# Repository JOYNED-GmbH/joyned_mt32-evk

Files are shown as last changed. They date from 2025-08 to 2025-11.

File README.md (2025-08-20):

This is a hardware reference design for a fully compliant Milan endpoint. It converts from a AVB/Milan network to I2S or TDM and vice versa.
Please feel free to copy and modify for your individual needs. This hardware reference design is published under the Creative Commons License. For software licensing visit www.joyned.at

Portmap Spreadsheet: https://docs.google.com/spreadsheets/d/1wGiAsmqoAx-SCyp8chBWGLcsXNjXNMac/edit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

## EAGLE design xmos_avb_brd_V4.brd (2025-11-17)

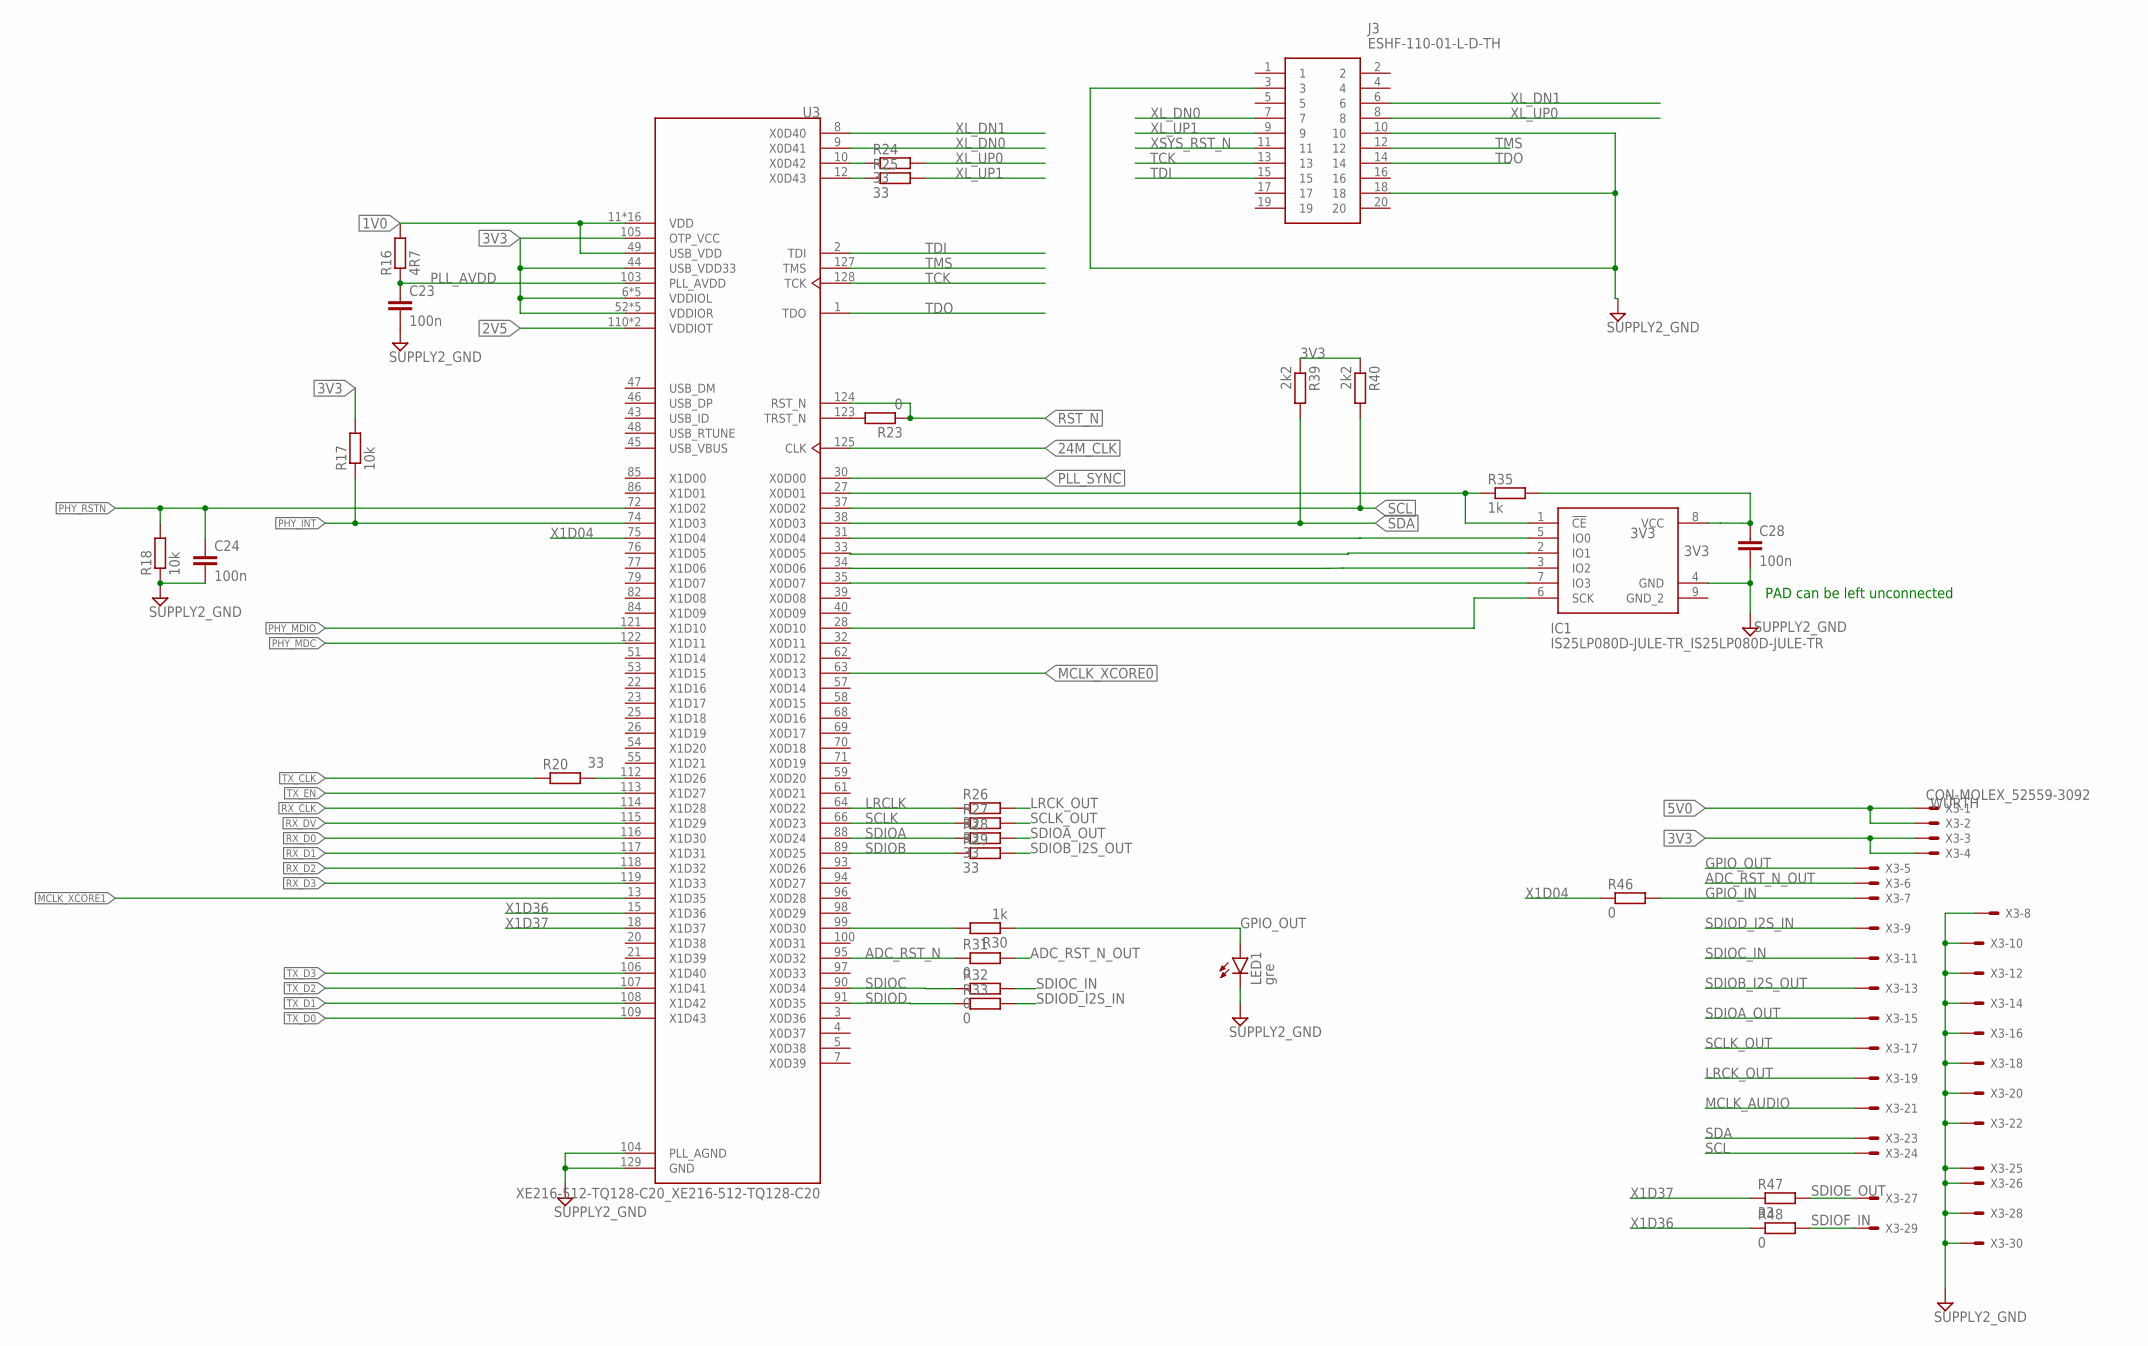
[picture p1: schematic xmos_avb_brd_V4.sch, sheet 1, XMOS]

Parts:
C23, C24, C28: 100n; RCL_C0402
IC1: IS25LP080D-JULE-TR_IS25LP080D-JULE-TR; IS25LP080D-JULE-TR_SON50P300X200X55-9N
J3: ESHF-110-01-L-D-TH; SHDR20W41P127_2X10_1905X559X54
LED1: gre; LED_CHIP-LED0603
R16: 4R7; RCL_R0402
R17, R18: 10k; RCL_R0402
R20, R24, R25, R26, R27, R28, R29, R47: 33; RCL_R0402
R23, R31, R32, R33, R46, R48: 0; RCL_R0402
R30, R35: 1k; RCL_R0402
R39, R40: 2k2; RCL_R0402
U3: XE216-512-TQ128-C20_XE216-512-TQ128-C20; XE216-512-TQ128-C20_QFP40P1600X1600X120-129N
X3: CON-MOLEX_52559-3092; MPN 687330124422

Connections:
1V0: R16.2, U3.11 (VDD), U3.16 (VDD), U3.17 (VDD), U3.24 (VDD), U3.36 (VDD), U3.41 (VDD), U3.49 (USB_VDD), U3.56 (VDD), U3.60 (VDD), U3.73 (VDD), U3.80 (VDD), U3.81 (VDD), U3.87 (VDD), U3.101 (VDD), U3.102 (VDD), U3.120 (VDD), U3.126 (VDD); also elsewhere on the board
2V5: U3.110 (VDDIOT), U3.111 (VDDIOT); also elsewhere on the board
3V3: C28.1, IC1.8 (VCC), R17.2, R35.2, R39.1, R40.1, U3.6 (VDDIOL), U3.14 (VDDIOL), U3.19 (VDDIOL), U3.29 (VDDIOL), U3.42 (VDDIOL), U3.44 (USB_VDD33), U3.52 (VDDIOR), U3.67 (VDDIOR), U3.78 (VDDIOR), U3.83 (VDDIOR), U3.92 (VDDIOR), U3.105 (OTP_VCC), X3.3, X3.4; also elsewhere on the board
5V0: X3.1, X3.2; also elsewhere on the board
24M_CLK: U3.125 (CLK); also elsewhere on the board
ADC_RST_N: R31.1, U3.95 (X0D32)
ADC_RST_N_OUT: R31.2, X3.6
GND: C23.2, C24.2, C28.2, IC1.4 (GND), J3.3, J3.10, J3.18, LED1.C, R18.1, U3.104 (PLL_AGND), U3.129 (GND), X3.8, X3.10, X3.12, X3.14, X3.16, X3.18, X3.20, X3.22, X3.25, X3.26, X3.28, X3.30; also elsewhere on the board
GPIO_IN: R46.2, X3.7
GPIO_OUT: LED1.A, R30.1, X3.5
LRCK_OUT: R26.2, X3.19
LRCLK: R26.1, U3.64 (X0D22)
MCLK_AUDIO: X3.21; also elsewhere on the board
MCLK_XCORE0: U3.63 (X0D13); also elsewhere on the board
MCLK_XCORE1: U3.13 (X1D35); also elsewhere on the board
unnamed: R30.2, U3.99 (X0D30)
unnamed: IC1.6 (SCK), U3.28 (X0D10)
unnamed: IC1.5 (IO0), U3.31 (X0D04)
unnamed: IC1.2 (IO1), U3.33 (X0D05)
unnamed: IC1.3 (IO2), U3.34 (X0D06)
unnamed: R20.2, U3.112 (X1D26)
unnamed: IC1.7 (IO3), U3.35 (X0D07)
unnamed: R24.1, U3.10 (X0D42)
unnamed: R25.1, U3.12 (X0D43)
unnamed: R23.2, U3.123 (TRST_N)
PHY_INT: R17.1, U3.74 (X1D03); also elsewhere on the board
PHY_MDC: U3.122 (X1D11); also elsewhere on the board
PHY_MDIO: U3.121 (X1D10); also elsewhere on the board
PHY_RSTN: C24.1, R18.2, U3.72 (X1D02); also elsewhere on the board
PLL_AVDD: C23.1, R16.1, U3.103 (PLL_AVDD)
PLL_SYNC: U3.30 (X0D00); also elsewhere on the board
RST_N: R23.1, U3.124 (RST_N); also elsewhere on the board
RX_CLK: U3.114 (X1D28); also elsewhere on the board
RX_D0: U3.116 (X1D30); also elsewhere on the board
RX_D1: U3.117 (X1D31); also elsewhere on the board
RX_D2: U3.118 (X1D32); also elsewhere on the board
RX_D3: U3.119 (X1D33); also elsewhere on the board
RX_DV: U3.115 (X1D29); also elsewhere on the board
SCL: R40.2, U3.37 (X0D02), X3.24; also elsewhere on the board
SCLK: R27.1, U3.66 (X0D23)
SCLK_OUT: R27.2, X3.17
SDA: R39.2, U3.38 (X0D03), X3.23; also elsewhere on the board
SDIOA: R28.1, U3.88 (X0D24)
SDIOA_OUT: R28.2, X3.15
SDIOB: R29.1, U3.89 (X0D25)
SDIOB_I2S_OUT: R29.2, X3.13
SDIOC: R32.1, U3.90 (X0D34)
SDIOC_IN: R32.2, X3.11
SDIOD: R33.1, U3.91 (X0D35)
SDIOD_I2S_IN: R33.2, X3.9
SDIOE_OUT: R47.2, X3.27
SDIOF_IN: R48.2, X3.29
SPI_CS: IC1.1 (!CE), R35.1, U3.27 (X0D01)
TCK: J3.13, U3.128 (TCK)
TDI: J3.15, U3.2 (TDI)
TDO: J3.14, U3.1 (TDO)
TMS: J3.12, U3.127 (TMS)
TX_CLK: R20.1; also elsewhere on the board
TX_D0: U3.109 (X1D43); also elsewhere on the board
TX_D1: U3.108 (X1D42); also elsewhere on the board
TX_D2: U3.107 (X1D41); also elsewhere on the board
TX_D3: U3.106 (X1D40); also elsewhere on the board
TX_EN: U3.113 (X1D27); also elsewhere on the board
X1D04: R46.1, U3.75 (X1D04)
X1D36: R48.1, U3.15 (X1D36)
X1D37: R47.1, U3.18 (X1D37)
XL_DN0: J3.7, U3.9 (X0D41)
XL_DN1: J3.6, U3.8 (X0D40)
XL_UP0: J3.8, R24.2
XL_UP1: J3.9, R25.2
XSYS_RST_N: J3.11; also elsewhere on the board

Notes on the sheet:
PAD can be left unconnected

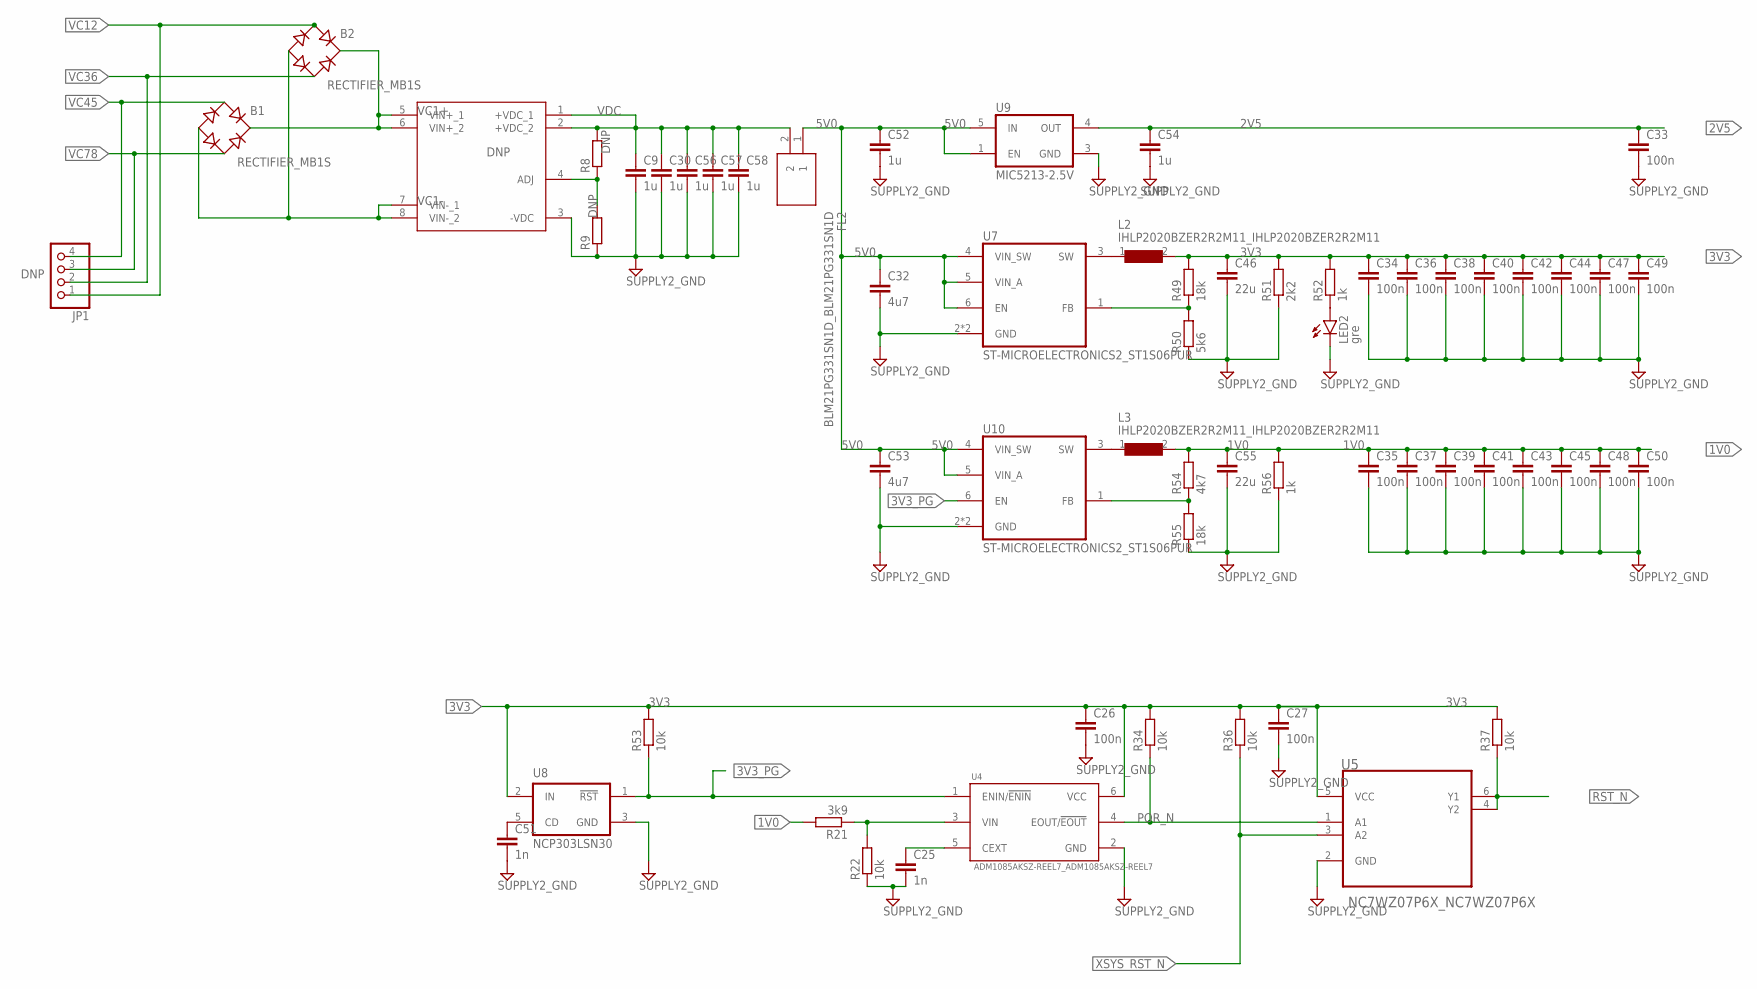
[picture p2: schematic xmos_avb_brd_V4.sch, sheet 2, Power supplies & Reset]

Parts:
B1, B2: RECTIFIER_MB1S; RECTIFIER_SOIC-4
C9, C30, C52, C54, C56, C57, C58: 1u; RCL_C1206
C25, C51: 1n; RCL_C0402
C26, C27, C33, C34, C35, C36, C37, C38, C39, C40, C41, C42, C43, C44, C45, C47, C48, C49, C50: 100n; RCL_C0402
C32, C53: 4u7; RCL_C1206
C46, C55: 22u; RCL_C1206
FL2: BLM21PG331SN1D_BLM21PG331SN1D; BLM21PG331SN1D_BEADC2012X105N
JP1: PINHEAD_PINHD-1X4; PINHEAD_1X04
L2, L3: IHLP2020BZER2R2M11_IHLP2020BZER2R2M11; IHLP2020BZER2R2M11_INDPM5552X200N
LED2: gre; LED_CHIP-LED0603
R8, R9: RCL_R-EU_R0402; RCL_R0402
R21: 3k9; RCL_R0402
R22, R34, R36, R37, R53: 10k; RCL_R0402
R49, R55: 18k; RCL_R0402
R50: 5k6; RCL_R0402
R51: 2k2; RCL_R0402
R52, R56: 1k; RCL_R0402
R54: 4k7; RCL_R0402
U1: AG9900_AG9905LP; AG9900_AG9900LP
U4: ADM1085AKSZ-REEL7_ADM1085AKSZ-REEL7; ADM1085AKSZ-REEL7_SOP65P210X95-6N
U5: NC7WZ07P6X_NC7WZ07P6X; NC7WZ07P6X_SOT65P210X110-6N
U7, U10: ST-MICROELECTRONICS2_ST1S06PUR; ST-MICROELECTRONICS2_DFN6
U8: NCP303LSN30; ON-SEMI_SOT23-5
U9: MIC5213-2.5V; MICREL2_SC70-5

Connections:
1V0: C35.1, C37.1, C39.1, C41.1, C43.1, C45.1, C48.1, C50.1, C55.1, L3.2, R21.2, R54.2, R56.2; also elsewhere on the board
2V5: C33.1, C54.1, U9.4 (OUT); also elsewhere on the board
3V3: C26.1, C27.1, C34.1, C36.1, C38.1, C40.1, C42.1, C44.1, C46.1, C47.1, C49.1, L2.2, R34.2, R36.2, R37.2, R49.2, R51.2, R52.2, R53.2, U4.6 (VCC), U5.5 (VCC), U8.2 (IN); also elsewhere on the board
3V3_PG: R53.1, U4.1 (ENIN/!ENIN), U8.1 (!RST!), U10.6 (EN)
5V0: C32.1, C52.1, C53.1, FL2.1, U7.4 (VIN_SW), U7.5 (VIN_A), U7.6 (EN), U9.1 (EN), U9.5 (IN), U10.4 (VIN_SW), U10.5 (VIN_A); also elsewhere on the board
GND: C9.2, C25.2, C26.2, C27.2, C30.2, C32.2, C33.2, C34.2, C35.2, C36.2, C37.2, C38.2, C39.2, C40.2, C41.2, C42.2, C43.2, C44.2, C45.2, C46.2, C47.2, C48.2, C49.2, C50.2, C51.2, C52.2, C53.2, C54.2, C55.2, C56.2, C57.2, C58.2, LED2.C, R9.1, R22.1, R50.1, R51.1, R55.1, R56.1, U1.3 (-VDC), U4.2 (GND), U5.2 (GND), U7.2 (GND), U7.7 (GND), U8.3 (GND), U9.3 (GND), U10.2 (GND), U10.7 (GND); also elsewhere on the board
unnamed: R21.1, R22.2, U4.3 (VIN)
unnamed: R8.1, R9.2, U1.4 (ADJ)
unnamed: L2.1, U7.3 (SW)
unnamed: L3.1, U10.3 (SW)
unnamed: C25.1, U4.5 (CEXT)
unnamed: R54.1, R55.2, U10.1 (FB)
unnamed: C51.1, U8.5 (CD)
unnamed: R49.1, R50.2, U7.1 (FB)
unnamed: LED2.A, R52.1
POR_N: R34.1, U4.4 (EOUT/!EOUT), U5.1 (A1)
RST_N: R37.1, U5.4 (Y2), U5.6 (Y1); also elsewhere on the board
VC1+: B1.+, B2.+, U1.5 (VIN+_1), U1.6 (VIN+_2)
VC1-: B1.-, B2.-, U1.7 (VIN-_1), U1.8 (VIN-_2)
VC12: B2.~1 (AC1), JP1.1; also elsewhere on the board
VC36: B2.~2 (AC2), JP1.2; also elsewhere on the board
VC45: B1.~1 (AC1), JP1.4; also elsewhere on the board
VC78: B1.~2 (AC2), JP1.3; also elsewhere on the board
VDC: C9.1, C30.1, C56.1, C57.1, C58.1, FL2.2, R8.2, U1.1 (+VDC_1), U1.2 (+VDC_2)
XSYS_RST_N: R36.1, U5.3 (A2); also elsewhere on the board

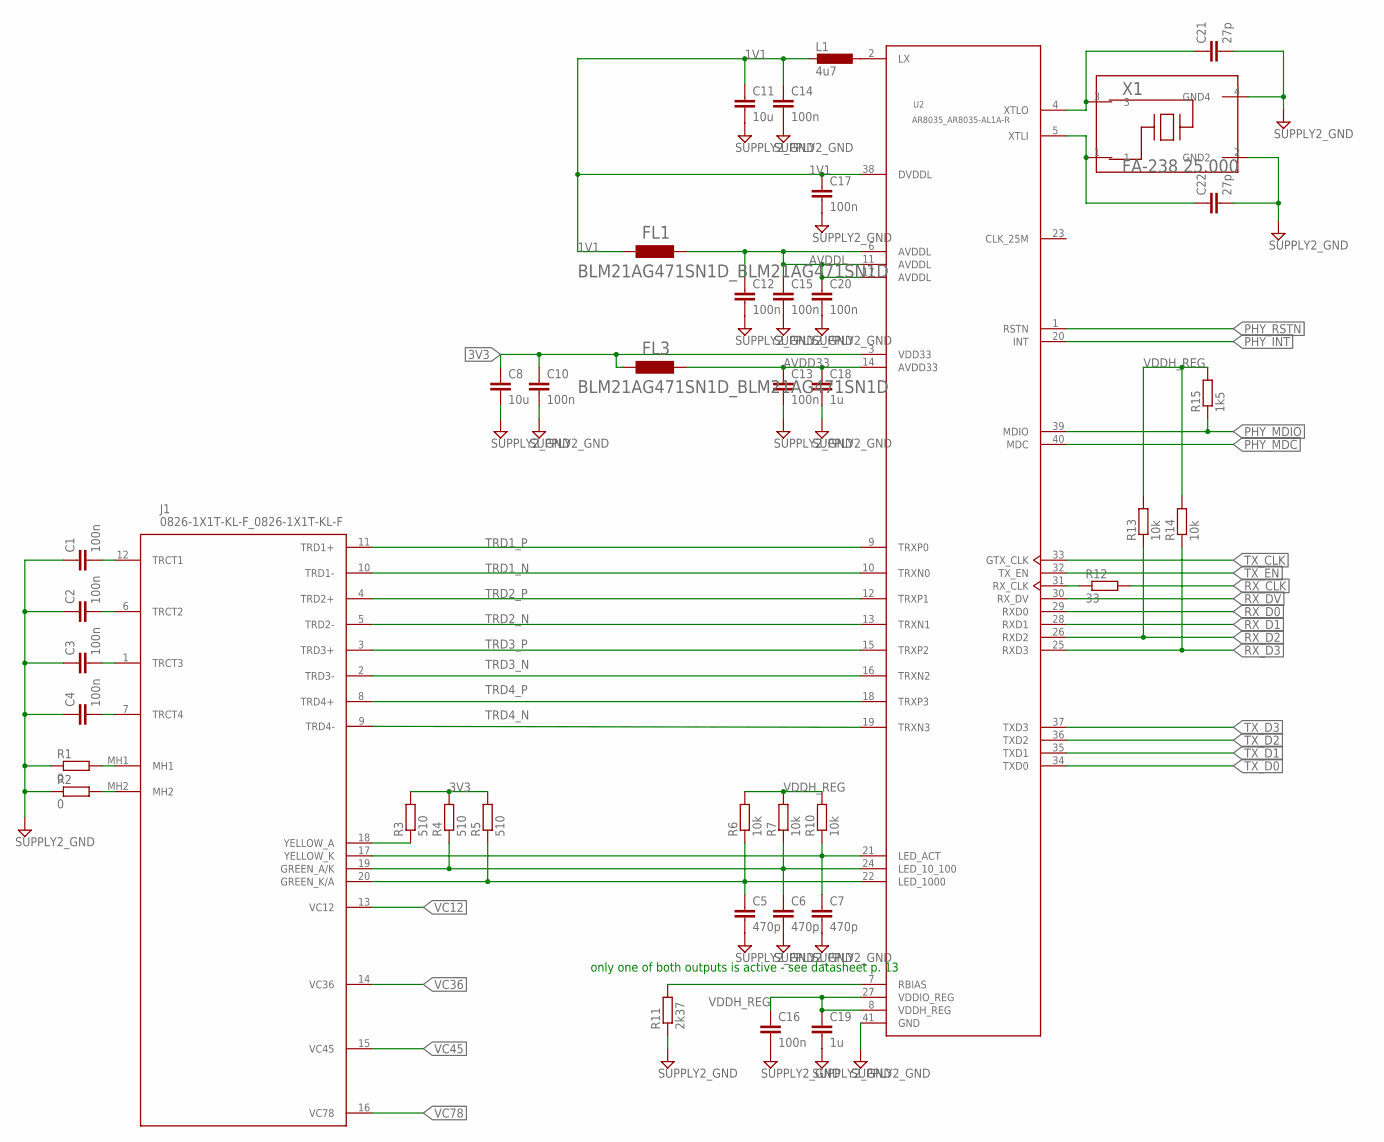
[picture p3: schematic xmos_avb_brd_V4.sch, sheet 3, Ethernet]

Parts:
C1, C2, C3, C4, C10, C12, C13, C14, C15, C16, C17, C20: 100n; RCL_C0402
C5, C6, C7: 470p; RCL_C0402
C8, C11: 10u; RCL_C1206
C18, C19: 1u; RCL_C1206
C21, C22: 27p; RCL_C0402
FL1, FL3: BLM21AG471SN1D_BLM21AG471SN1D; BLM21AG471SN1D_BEADC2012X105N
J1: 0826-1X1T-KL-F_0826-1X1T-KL-F; 0826-1X1T-KL-F_08261X1TKLF
L1: 4u7; RCL_L2012C
R1, R2: 0; RCL_R0402
R3, R4, R5: 510; RCL_R0402
R6, R7, R10, R13, R14: 10k; RCL_R0402
R11: 2k37; RCL_R0402
R12: 33; RCL_R0402
R15: 1k5; RCL_R0402
U2: AR8035_AR8035-AL1A-R; AR8035_QFN40P500X500X75-41N
X1: FA-238 25.000; FA-238_OSCCC320X250X70-4N

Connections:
1V1: C11.1, C14.1, C17.1, FL1.1, L1.2, U2.38 (DVDDL)
3V3: C8.1, C10.1, FL3.1, R3.2, R4.2, R5.2, U2.3 (VDD33); also elsewhere on the board
AVDD33: C13.1, C18.1, FL3.2, U2.14 (AVDD33)
AVDDL: C12.1, C15.1, C20.1, FL1.2, U2.6 (AVDDL), U2.11 (AVDDL), U2.17 (AVDDL)
GND: C1.1, C2.1, C3.1, C4.1, C5.2, C6.2, C7.2, C8.2, C10.2, C11.2, C12.2, C13.2, C14.2, C15.2, C16.2, C17.2, C18.2, C19.2, C20.2, C21.2, C22.2, R1.1, R2.1, R11.1, U2.41 (GND), X1.2 (GND2), X1.4 (GND4); also elsewhere on the board
unnamed: L1.1, U2.2 (LX)
unnamed: J1.MH1, R1.2
unnamed: C6.1, J1.19 (GREEN_A/K), R4.1, R7.1, U2.24 (LED_10_100)
unnamed: J1.18 (YELLOW_A), R3.1
unnamed: C21.1, U2.4 (XTLO), X1.3
unnamed: C22.1, U2.5 (XTLI), X1.1
unnamed: R12.1, U2.31 (RX_CLK)
unnamed: C7.1, J1.17 (YELLOW_K), R10.1, U2.21 (LED_ACT)
unnamed: C1.2, J1.12 (TRCT1)
unnamed: C2.2, J1.6 (TRCT2)
unnamed: R11.2, U2.7 (RBIAS)
unnamed: C5.1, J1.20 (GREEN_K/A), R5.1, R6.1, U2.22 (LED_1000)
unnamed: C3.2, J1.1 (TRCT3)
unnamed: C4.2, J1.7 (TRCT4)
unnamed: J1.MH2, R2.2
PHY_INT: U2.20 (INT); also elsewhere on the board
PHY_MDC: U2.40 (MDC); also elsewhere on the board
PHY_MDIO: R15.1, U2.39 (MDIO); also elsewhere on the board
PHY_RSTN: U2.1 (RSTN); also elsewhere on the board
RX_CLK: R12.2; also elsewhere on the board
RX_D0: U2.29 (RXD0); also elsewhere on the board
RX_D1: U2.28 (RXD1); also elsewhere on the board
RX_D2: R13.1, U2.26 (RXD2); also elsewhere on the board
RX_D3: R14.1, U2.25 (RXD3); also elsewhere on the board
RX_DV: U2.30 (RX_DV); also elsewhere on the board
TRD1_N: J1.10 (TRD1-), U2.10 (TRXN0)
TRD1_P: J1.11 (TRD1+), U2.9 (TRXP0)
TRD2_N: J1.5 (TRD2-), U2.13 (TRXN1)
TRD2_P: J1.4 (TRD2+), U2.12 (TRXP1)
TRD3_N: J1.2 (TRD3-), U2.16 (TRXN2)
TRD3_P: J1.3 (TRD3+), U2.15 (TRXP2)
TRD4_N: J1.9 (TRD4-), U2.19 (TRXN3)
TRD4_P: J1.8 (TRD4+), U2.18 (TRXP3)
TX_CLK: U2.33 (GTX_CLK); also elsewhere on the board
TX_D0: U2.34 (TXD0); also elsewhere on the board
TX_D1: U2.35 (TXD1); also elsewhere on the board
TX_D2: U2.36 (TXD2); also elsewhere on the board
TX_D3: U2.37 (TXD3); also elsewhere on the board
TX_EN: U2.32 (TX_EN); also elsewhere on the board
VC12: J1.13 (VC12); also elsewhere on the board
VC36: J1.14 (VC36); also elsewhere on the board
VC45: J1.15 (VC45); also elsewhere on the board
VC78: J1.16 (VC78); also elsewhere on the board
VDDH_REG: C16.1, C19.1, R6.2, R7.2, R10.2, R13.2, R14.2, R15.2, U2.8 (VDDH_REG), U2.27 (VDDIO_REG)

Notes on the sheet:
only one of both outputs is active - see datasheet p. 13

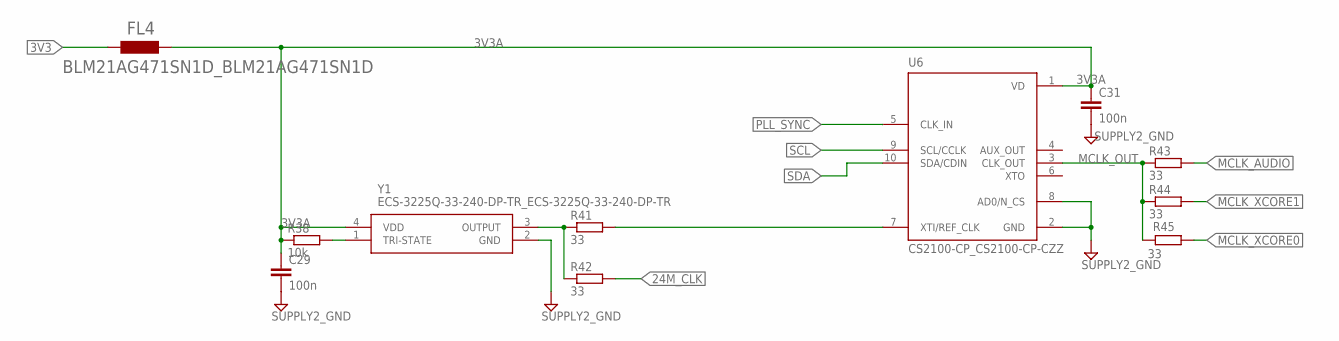
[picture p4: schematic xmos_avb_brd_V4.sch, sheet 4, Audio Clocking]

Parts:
C29, C31: 100n; RCL_C0402
FL4: BLM21AG471SN1D_BLM21AG471SN1D; BLM21AG471SN1D_BEADC2012X105N
R38: 10k; RCL_R0402
R41, R42, R43, R44, R45: 33; RCL_R0402
U6: CS2100-CP_CS2100-CP-CZZ; CS2100-CP_CIRRUS-LOGIC_MSOP10
Y1: ECS-3225Q-33-240-DP-TR_ECS-3225Q-33-240-DP-TR; ECS-3225Q-33-240-DP-TR_ECS3225Q33240DPTR

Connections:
3V3: FL4.1; also elsewhere on the board
3V3A: C29.1, C31.1, FL4.2, R38.1, U6.1 (VD), Y1.4 (VDD)
24M_CLK: R42.2; also elsewhere on the board
GND: C29.2, C31.2, U6.2 (GND), U6.8 (AD0/N_CS), Y1.2 (GND); also elsewhere on the board
MCLK_AUDIO: R43.2; also elsewhere on the board
MCLK_OUT: R43.1, R44.1, R45.2, U6.3 (CLK_OUT)
MCLK_XCORE0: R45.1; also elsewhere on the board
MCLK_XCORE1: R44.2; also elsewhere on the board
unnamed: R41.1, R42.1, Y1.3 (OUTPUT)
unnamed: R41.2, U6.7 (XTI/REF_CLK)
unnamed: R38.2, Y1.1 (TRI-STATE)
PLL_SYNC: U6.5 (CLK_IN); also elsewhere on the board
SCL: U6.9 (SCL/CCLK); also elsewhere on the board
SDA: U6.10 (SDA/CDIN); also elsewhere on the board

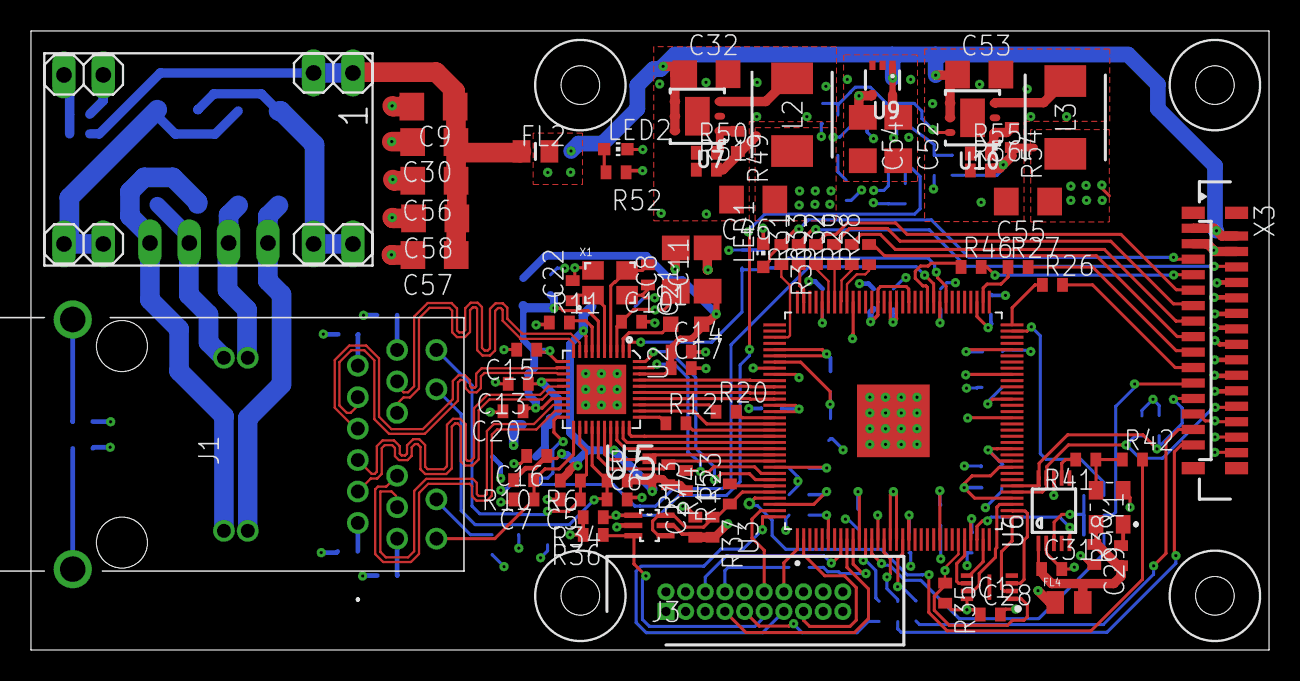
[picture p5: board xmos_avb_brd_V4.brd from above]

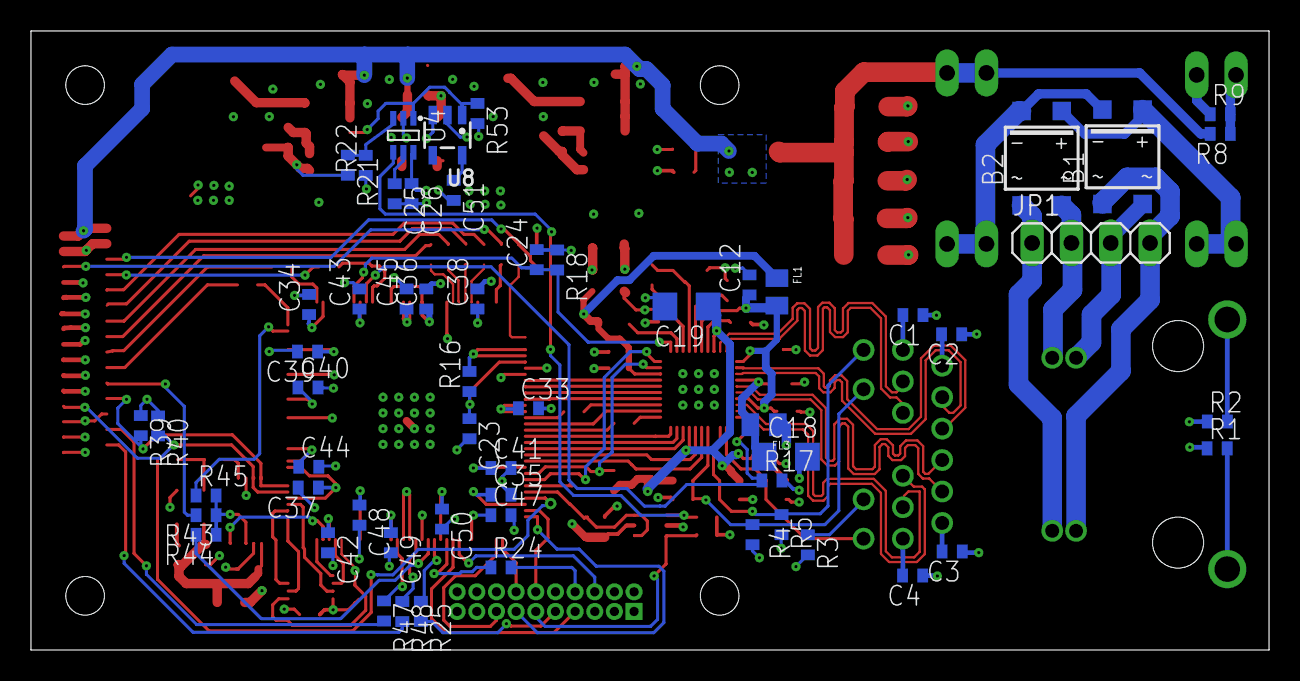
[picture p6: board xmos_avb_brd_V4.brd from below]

Board: 4 copper layers, 80.0 x 40.0 mm, 145 parts (58 on the bottom side), 121 nets.

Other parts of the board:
U$4, U$5, U$6, U$7: DRIL-2,5

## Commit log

2025-11-14 new debug header added to improve debugging with xmos. old tag-connect removed.
    [xmos_avb_brd_V4.brd, xmos_avb_brd_V4.sch]
2025-11-17 resolved DRC errors and exported manufacturing data for V4.
    [xmos_avb_brd_V4.brd, xmos_avb_brd_V4.sch]
